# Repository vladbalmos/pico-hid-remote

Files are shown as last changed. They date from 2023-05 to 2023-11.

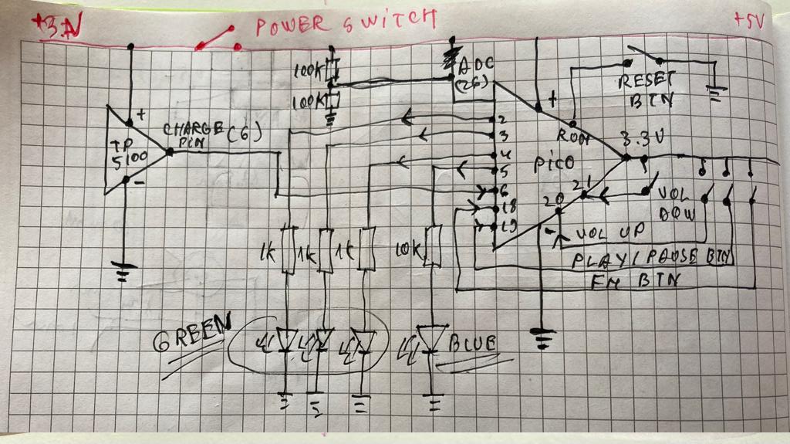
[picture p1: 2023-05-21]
hw/schematic.jpeg

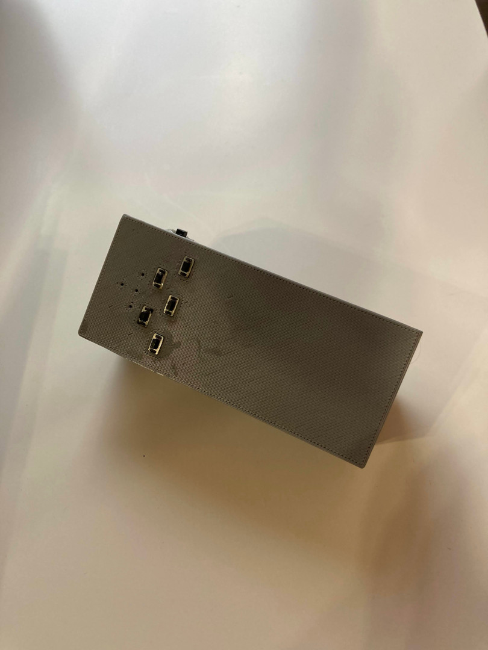
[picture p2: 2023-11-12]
hw/case/case-v1.jpeg

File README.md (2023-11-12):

## HID Bluetooth Remote

HID Bluetooth (BLE) Remote based on a Pico W.

case-v2-cover

## Hardware requirements

* Pico W
* 5 x micro switches
* TP5100 charging module
* micro USB female
* 1 x 18650 lithium battery (for the V1 enclosure)
* 1 x blackberry q10 lithium battery (for the V2 enclosure)
* 1 x 3mm blue LED + 10k resistor
* 3 x 3mm green LED + 3 x 1k resistors
* 2 x 100k resistors
* pico probe (optional)

## Software dependencies

* pico-sdk (1.5.0)
* pico-extras
* opencd (optional)
* pico probe (optional)

## Build

    make build
    
## Install
Via pico probe:

    make install

## Buttons

* FN
    - long press - turn off
    - double press - show baterry level
    
* PLAY
    - wakeup from sleep if sleeping
    - toggle play/pause
    
* VOL UP
    - increase volume

* VOL DOWN
    - decrease volume

* RESET
    - reset PICO
    
## Behaviour
    
On startup the device is discoverable for one minute, after which, if not paired, the device will go to sleep to preserve battery.

If the device is paired, discoverability is turned off until disconnected.

Once paired, the device will go to sleep if no button press was detected in 10 minutes in order to preserve battery.

### LEDs

* blue
    - flashes while not connected and in pairing mode
    - off once paired
    
* 3 x green
    - show battery level
    - if battery level <= 5% the last led in will flash for 5 seconds

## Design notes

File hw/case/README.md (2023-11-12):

There's two versions for the enclosure, the original designed around a 18650 battery and a protoboard and an updated version designed for a proper PCB and a battery taken from an old BlackBerry Q10 phone.

Both versions have their issues. The V1's overall size is a little to small for the amount of wires inside and the thin walls make it flex and doesn't seal properly. Also the buttons had to be superglued to stay in place.

The V2 is a really tight fit because again I didn't account for the size of the jumper wires. Also some filing is required on the lid interior because I forgot to cut out some interior features of the model. If you're planning to print the second version, I recommend printing with supports on the inner side, in my case I printed it on the outer side with supports which were really hard to remove and required filing.

[Case V1](https://github.com/vladbalmos/pico-hid-remote/blob/master/hw/case/case-v1.jpeg)

[Case V2](https://github.com/vladbalmos/pico-hid-remote/blob/master/hw/case/case-v2.jpeg)

[V1 vs V2](https://github.com/vladbalmos/pico-hid-remote/blob/master/hw/case/case-v1-vs-v2.jpeg)

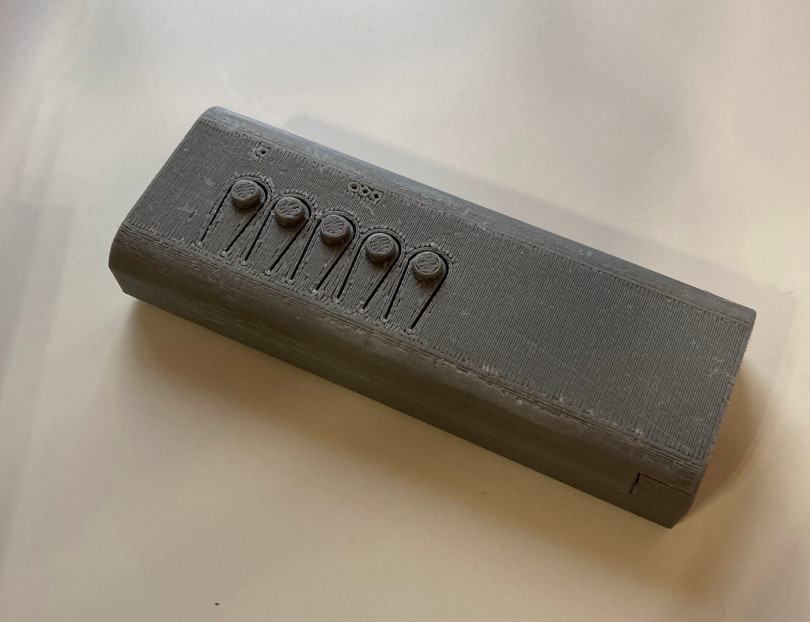
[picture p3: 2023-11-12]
hw/case/case-v2-cover.jpeg

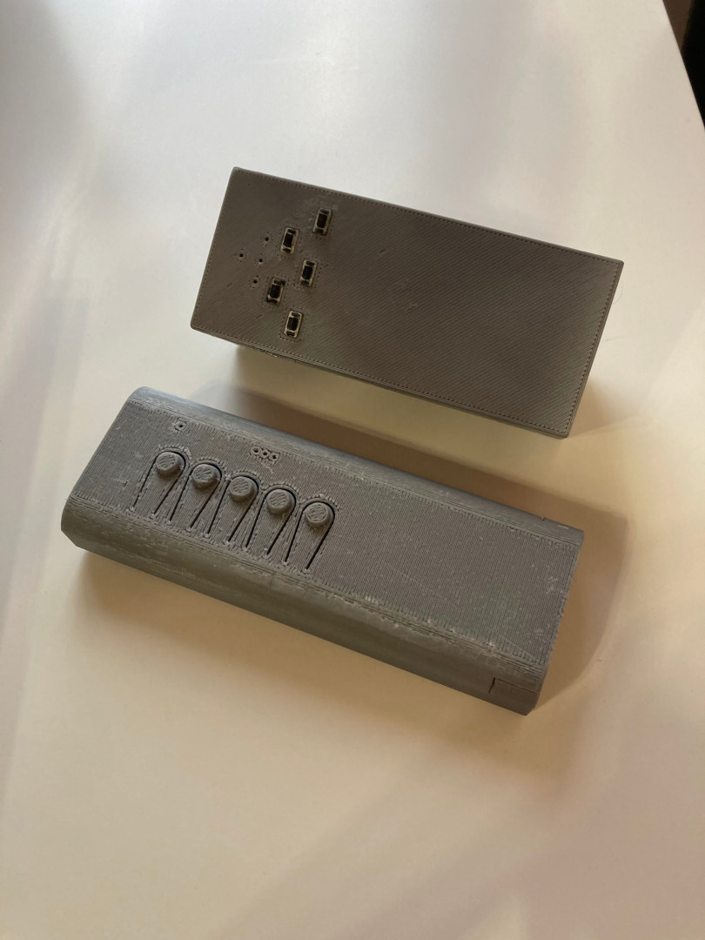
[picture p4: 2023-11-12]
hw/case/case-v1-vs-v2.jpeg

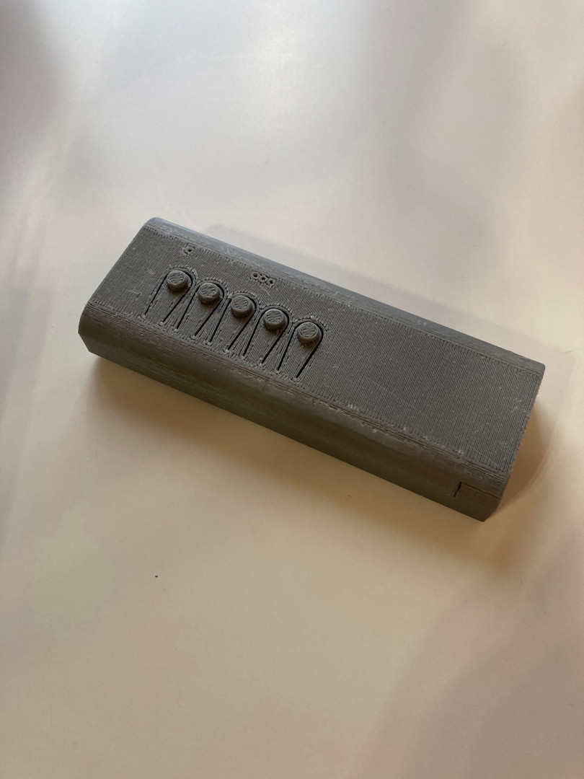
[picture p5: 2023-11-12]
hw/case/case-v2.jpeg

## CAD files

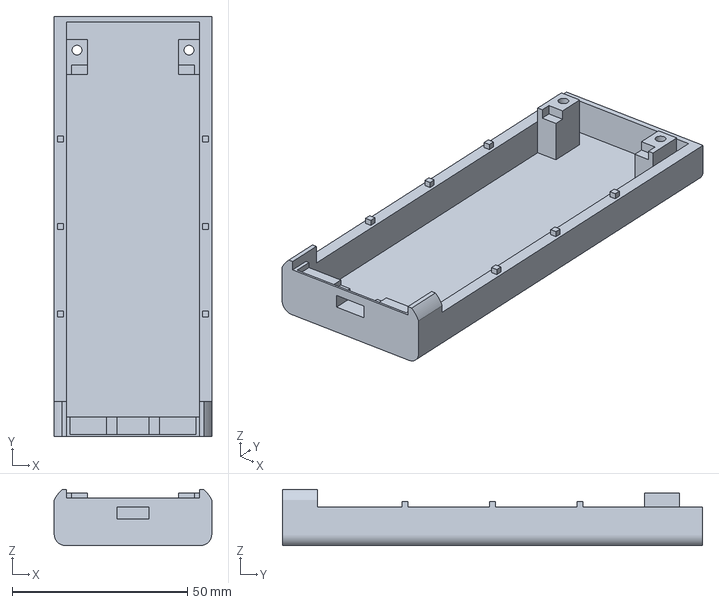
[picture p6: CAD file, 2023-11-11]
hw/case/case_v2-Case_Body.3mf
45.0 x 120.0 x 16.0 mm

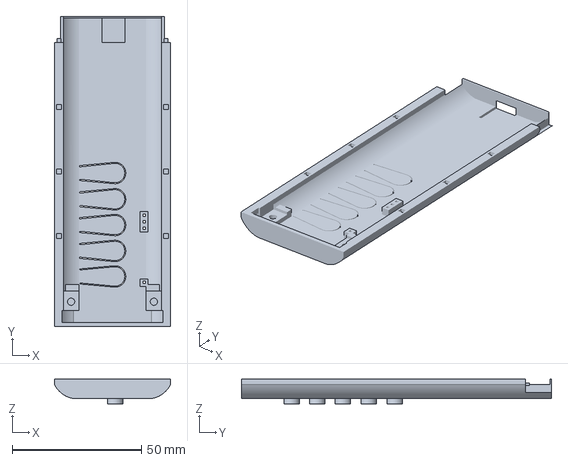
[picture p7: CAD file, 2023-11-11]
hw/case/case_v2-Lid_Body.3mf
45.0 x 120.0 x 9.50 mm

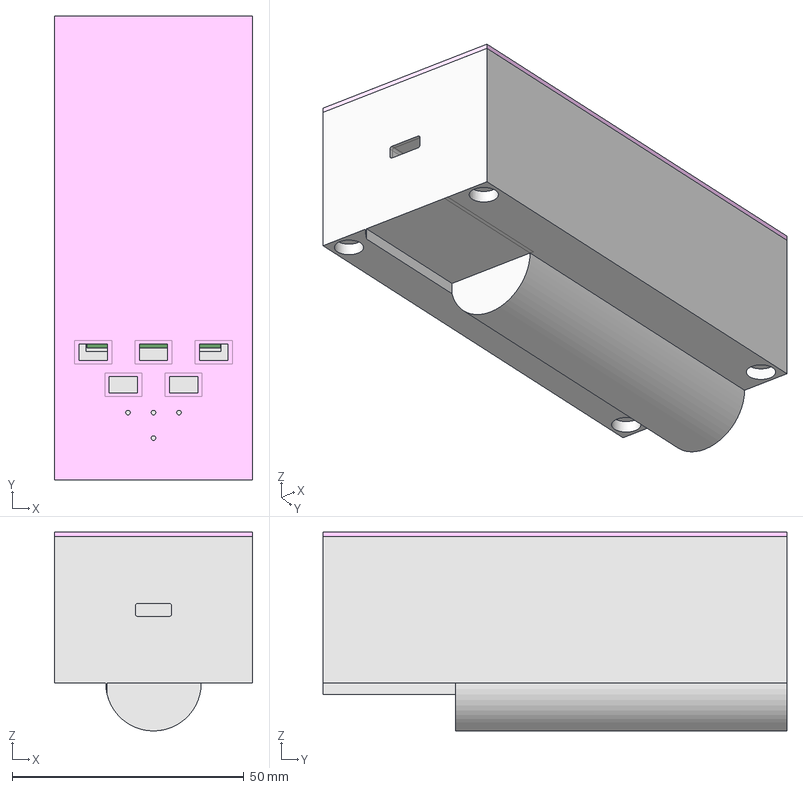
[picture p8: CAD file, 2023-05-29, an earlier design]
hw/case/case.FCStd
42.7 x 100.0 x 42.9 mm
Case_Body
Battery_Body
Body_PCB
Lid_Body

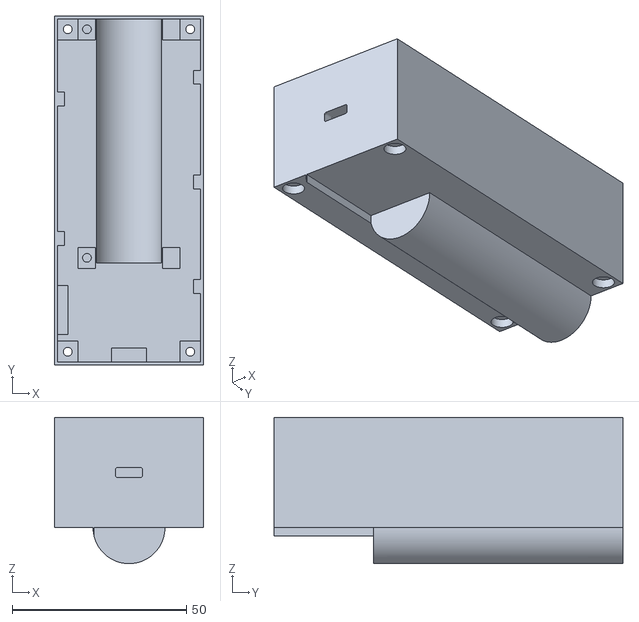
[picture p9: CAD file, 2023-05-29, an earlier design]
hw/case/case-Case_Body.stl
42.7 x 100.0 x 41.9

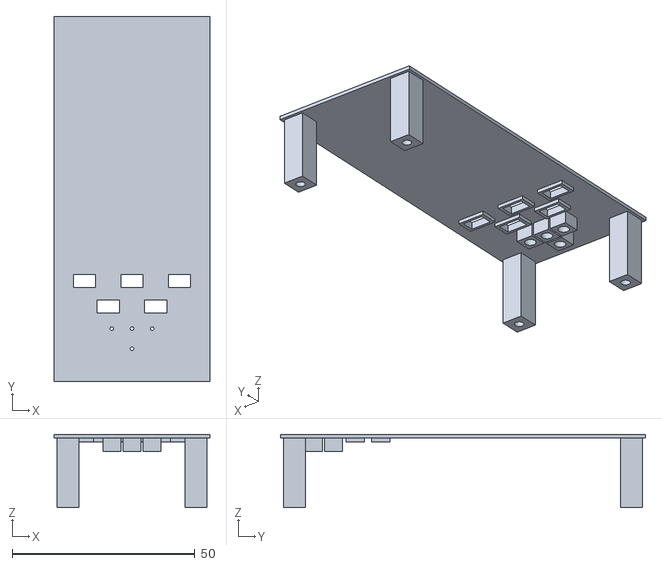
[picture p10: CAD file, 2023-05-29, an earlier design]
hw/case/case-Lid_Body.stl
42.7 x 100.0 x 20.0

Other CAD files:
hw/case/case_v2.FCStd
hw/case/case_v2-Case_Body.stl
hw/case/case_v2-Lid_Body.stl

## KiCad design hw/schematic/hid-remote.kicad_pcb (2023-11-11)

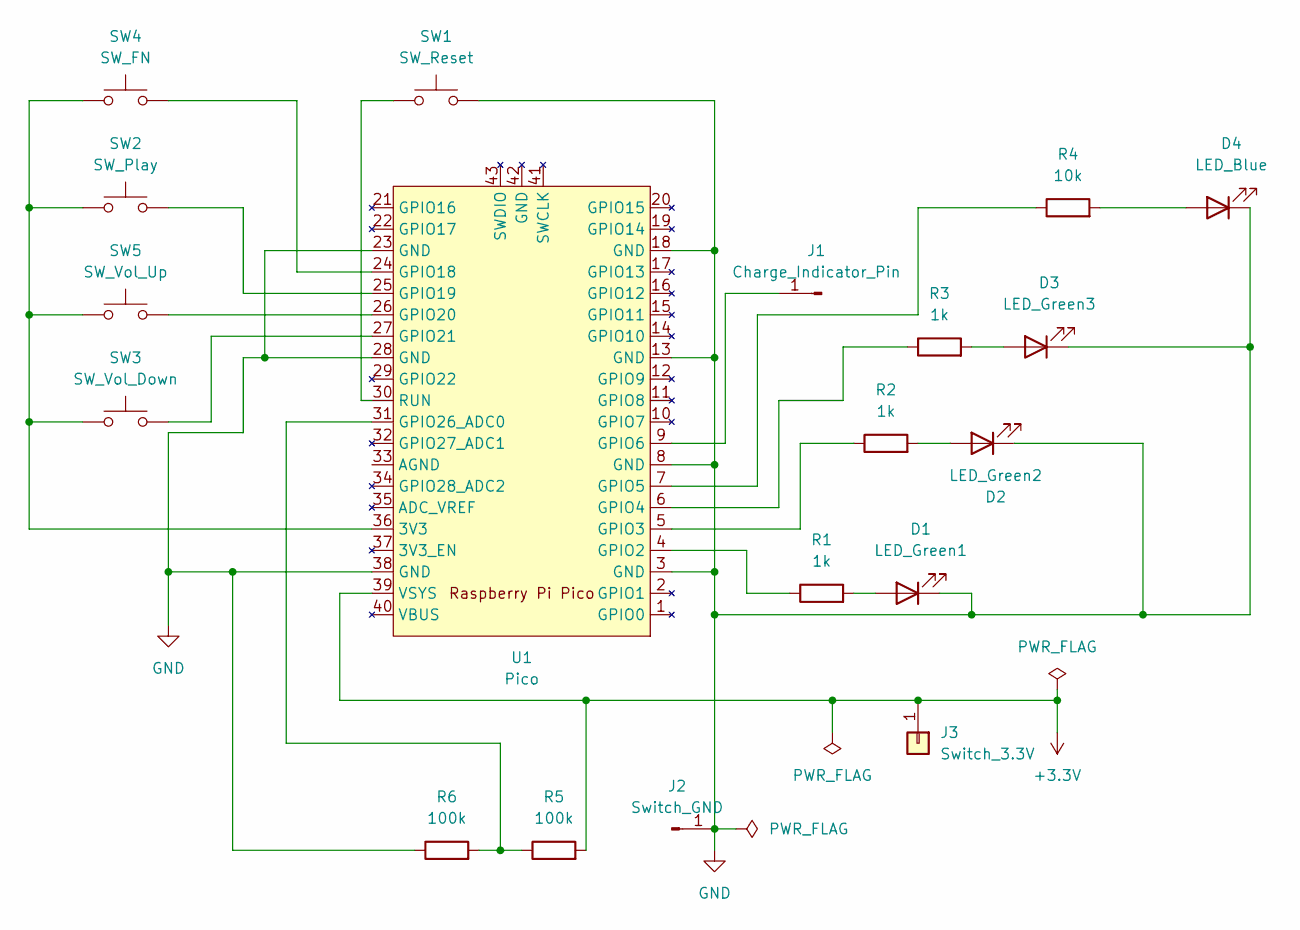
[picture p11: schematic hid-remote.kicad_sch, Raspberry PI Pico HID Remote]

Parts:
D1: LED_Green1; LED_0201_0603Metric_Pad0.64x0.40mm_HandSolder
D2: LED_Green2; LED_0201_0603Metric_Pad0.64x0.40mm_HandSolder
D3: LED_Green3; LED_0201_0603Metric_Pad0.64x0.40mm_HandSolder
D4: LED_Blue; LED_0201_0603Metric_Pad0.64x0.40mm_HandSolder
J1: Charge_Indicator_Pin; PinSocket_1x01_P2.54mm_Vertical
J2: Switch_GND; PinSocket_1x01_P2.54mm_Vertical
J3: Switch_3.3V; PinSocket_1x01_P2.54mm_Vertical
R1, R2, R3: 1k; R_Axial_DIN0204_L3.6mm_D1.6mm_P5.08mm_Horizontal
R4: 10k; R_Axial_DIN0207_L6.3mm_D2.5mm_P10.16mm_Horizontal
R5, R6: 100k; R_Axial_DIN0207_L6.3mm_D2.5mm_P10.16mm_Horizontal
SW1: SW_Reset; SW_Push_3x6x5
SW2: SW_Play; SW_Push_3x6x5
SW3: SW_Vol_Down; SW_Push_3x6x5
SW4: SW_FN; SW_Push_3x6x5
SW5: SW_Vol_Up; SW_Push_3x6x5
U1: Pico; RPi_Pico_SMD_TH

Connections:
+3.3V: J3.1, R5.2, U1.39 (VSYS)
GND: D1.1 (K), D2.1 (K), D3.1 (K), D4.1 (K), J2.1, R6.1, SW1.2, U1.3 (GND), U1.8 (GND), U1.13 (GND), U1.18 (GND), U1.23 (GND), U1.28 (GND), U1.38 (GND)
unnamed: D1.2 (A), R1.2
unnamed: D2.2 (A), R2.2
unnamed: D3.2 (A), R3.2
unnamed: D4.2 (A), R4.2
unnamed: J1.1, U1.9 (GPIO6)
unnamed: SW2.1, SW3.1, SW4.1, SW5.1, U1.36 (3V3)
unnamed: R1.1, U1.4 (GPIO2)
unnamed: R2.1, U1.5 (GPIO3)
unnamed: R3.1, U1.6 (GPIO4)
unnamed: R4.1, U1.7 (GPIO5)
unnamed: SW4.2, U1.24 (GPIO18)
unnamed: SW2.2, U1.25 (GPIO19)
unnamed: SW5.2, U1.26 (GPIO20)
unnamed: SW3.2, U1.27 (GPIO21)
unnamed: R5.1, R6.2, U1.31 (GPIO26_ADC0)
unnamed: SW1.1, U1.30 (RUN)

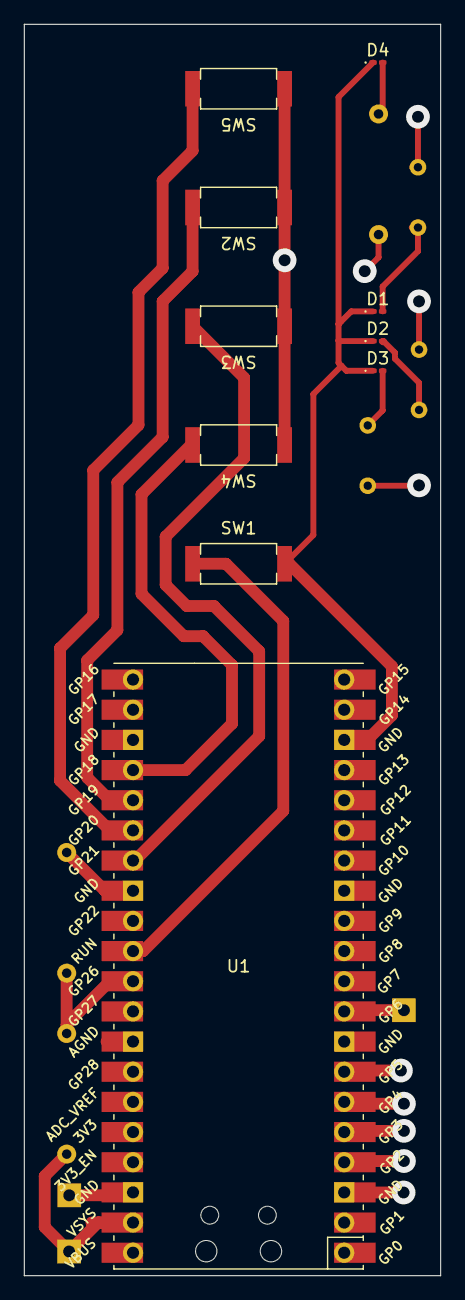
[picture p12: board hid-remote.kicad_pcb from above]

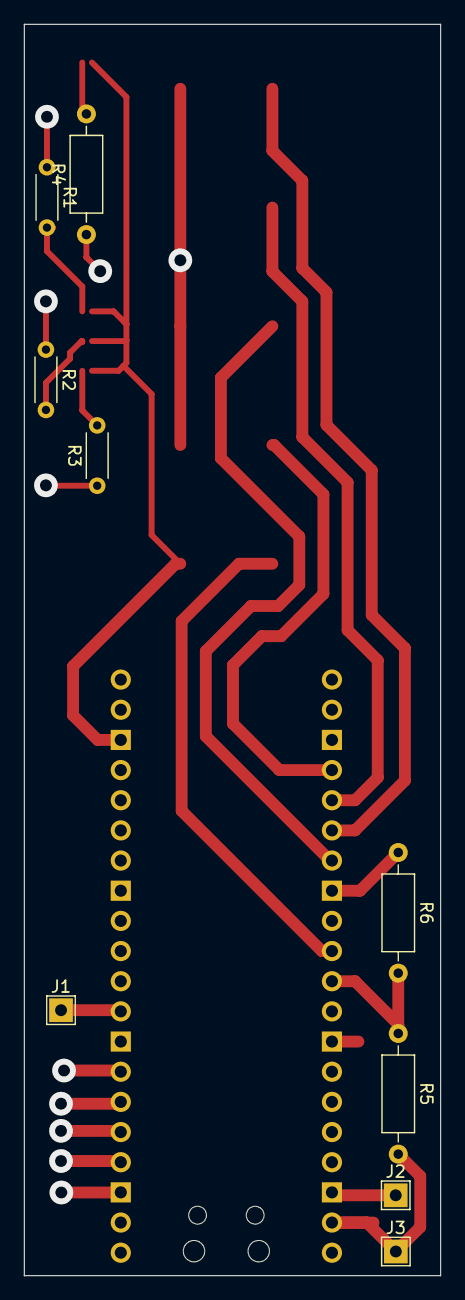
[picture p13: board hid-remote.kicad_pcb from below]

Board: 2 copper layers, 35.1 x 105.4 mm, 19 parts (9 on the bottom side), 18 nets.

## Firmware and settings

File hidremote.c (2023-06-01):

#include <stdio.h>
#include "pico/cyw43_arch.h"
#include "pico/sleep.h"
#include "hardware/clocks.h"
#include "hardware/pll.h"
#include "hardware/xosc.h"
#include "hardware/rosc.h"
#include "pico/util/queue.h"
#include "bt.h"
#include "buttons.h"
#include "control.h"
#include "battery.h"
#include "leds.h"
#include "debug.h"

#define ADC_PIN 26
#define MICRO_SLEEP_MS 10
#define BATTERY_CHECK_INTERVAL_S 10

#define CHARGE_PIN 6

static uint8_t pins[] = {FN_BTN_PIN, PLAY_CTRL_BTN_PIN, VOL_UP_BTN_PIN, VOL_DOWN_BTN_PIN};
static queue_t ctrl_ev_w_queue;
static queue_t ctrl_ev_r_queue;
static uint8_t bat_level;

extern uint8_t ctrl_is_connected;
extern absolute_time_t ctrl_disconnected_at;
extern absolute_time_t ctrl_last_command_at;

static void gpio_irq_handler(uint gpio, uint32_t event) {
    if (event == (GPIO_IRQ_EDGE_RISE | GPIO_IRQ_EDGE_FALL)) {
        return;
    }

    button_t *btn;
    uint8_t btn_action = 0;
    int8_t btn_pin = -1;
    
    btn_debounce(gpio, event, &btn_pin, &btn_action);
    
    if (btn_pin == -1) {
        return;
    }

    btn = btn_get(btn_pin);
    btn->pin = btn_pin;
    
    if (btn_action == BTN_PRESS) {
        btn->pressed_at = get_absolute_time();
    } else {
        btn->released_at = get_absolute_time();
    }
}

static int8_t deep_sleep() {
    // Flush stdio
    uart_default_tx_wait_blocking();
    
    // Prepare for sleep
    leds_turnoff();
    bt_deinit();
    cyw43_arch_deinit();
    ctrl_deinit();
    
    
    // Sleep until GPIO input
    sleep_run_from_rosc();
    sleep_goto_dormant_until_edge_high(PLAY_CTRL_BTN_PIN);
    
    // At this point we've woken up

    // Reset the clocks
    clocks_init();
    
    // Re-init stdio
    stdio_init_all();
    DEBUG("Woken up\n");
    uart_default_tx_wait_blocking();

    // Initialize BT
    if (cyw43_arch_init()) {
        DEBUG("Failed to initialise cyw43_arch\n");
        return -1;
    }
    bat_level = battery_level();
    bt_init(&ctrl_ev_r_queue, &ctrl_ev_w_queue, bat_level);
    ctrl_init(&ctrl_ev_w_queue, &ctrl_ev_r_queue);
    return 0;
}


int main() {
    button_t *btn;
    absolute_time_t now = nil_time;
    uint32_t now_s;
    uint32_t time_diff = 0;
    uint8_t battery_level_published = 0;

    stdio_init_all();

    // Init Bluetooth chipset
    if (cyw43_arch_init()) {
        printf("failed to initialise cyw43_arch\n");
        // TODO: check if power goes down when returning early
        return -1;
    }
    
    // Init buttons gpio pins
    for (uint8_t i = 0; i < 4; i++) {
        gpio_init(pins[i]);
        gpio_set_dir(pins[i], GPIO_IN);
        gpio_set_irq_enabled_with_callback(pins[i], GPIO_IRQ_EDGE_RISE | GPIO_IRQ_EDGE_FALL, true, &gpio_irq_handler);
    }
    
    // Init charge pin
    gpio_init(CHARGE_PIN);
    gpio_set_dir(CHARGE_PIN, GPIO_IN);

    // Init leds
    leds_init();
    
    queue_init(&ctrl_ev_w_queue, sizeof(ctrl_ev_t), 10);
    queue_init(&ctrl_ev_r_queue, sizeof(ctrl_ev_t), 10);

    // Init battery readings
    battery_init(ADC_PIN);
    bat_level = battery_level();
    
    // Init btstack
    bt_init(&ctrl_ev_r_queue, &ctrl_ev_w_queue, bat_level);

    // Init controller
    ctrl_init(&ctrl_ev_w_queue, &ctrl_ev_r_queue);
    
    // Init buttons
    btn_create_array();

    DEBUG("Remote initialized\n");
    leds_show_bt_connecting();
    
    while (1) {
        bt_process_queue();
        ctrl_process_queue();
        now = get_absolute_time();
        now_s = to_ms_since_boot(now) / 1000;

        if (gpio_get(CHARGE_PIN)) {
            DEBUG("Started battery charging. Stopping!\n");
            uart_default_tx_wait_blocking();
            break;
        }
        
        // Start checking battery level 10 seconds after boot
        if (now_s > 10 && bat_level <= 1) {
            DEBUG("Battery low! Please recharge! Stopping!\n");
            uart_default_tx_wait_blocking();
            break;
        }

        if (!ctrl_is_connected) {
            time_diff = absolute_time_diff_us(ctrl_disconnected_at, now) / 1000;
            if (time_diff >= CTRL_DEEP_SLEEP_TIMEOUT_MS) {
                DEBUG("Going to sleep due to lack of remote connection\n");
                deep_sleep();
                leds_show_bt_connecting();
                continue;
            }
        } else {
            // Check battery every 10 seconds
            if ((now_s % BATTERY_CHECK_INTERVAL_S) == 0) {
                if (!battery_level_published) {
                    bat_level = battery_level();
                    bt_set_battery_level(bat_level);
                    battery_level_published = 1;
                    DEBUG("Publishing battery level %d\n", bat_level);
                }
            } else {
                battery_level_published = 0;
            }

            if (ctrl_last_command_at) {
                time_diff = absolute_time_diff_us(ctrl_last_command_at, now) / 1000;
                if (time_diff >= CTRL_CMD_TIMEOUT_MS) {
                    DEBUG("Going to sleep due to inactivity\n");
                    deep_sleep();
                    leds_show_bt_connecting();
                    continue;
                }
            }
        }
        
        btn = btn_get(FN_BTN_PIN);

        if (btn_is_pressed(btn)) {
            if (btn_is_long_press(btn))  {
                btn_handled(btn, now);
                DEBUG("Going to sleep\n");
                if (deep_sleep() == -1) {
                    // Unable to re-initialize hardware
                    panic("Unable to safely wake up from sleep!");
                    break;
                }
                
                leds_show_bt_connecting();
                goto SLEEP;
            } else if (btn_is_double_press(btn)) {
                leds_show_battery_level(bat_level);
                DEBUG("Showing battery level\n");
            }
            goto SLEEP;
        }

        btn = btn_get(PLAY_CTRL_BTN_PIN);
        if (btn_is_pressed(btn)) {
            btn_handled(btn, now);
            ctrl_toggle_play_pause();
            goto SLEEP;
        }

        btn = btn_get(VOL_UP_BTN_PIN);
        if (btn_is_pressed(btn)) {
            btn_handled(btn, now);
            ctrl_vol_up();
            goto SLEEP;
        }

        btn = btn_get(VOL_DOWN_BTN_PIN);
        if (btn_is_pressed(btn)) {
            btn_handled(btn, now);
            ctrl_vol_down();
            goto SLEEP;
        }

        SLEEP:
            sleep_ms(MICRO_SLEEP_MS);
    }
    
    // Stop everything
    leds_turnoff();
    bt_deinit();
    ctrl_deinit();
    cyw43_arch_deinit();
    
    clock_configure(clk_ref,
                    CLOCKS_CLK_REF_CTRL_SRC_VALUE_ROSC_CLKSRC_PH,
                    0,
                    1 * MHZ,
                    1 * MHZ);
    clock_configure(clk_sys,
                    CLOCKS_CLK_SYS_CTRL_SRC_VALUE_CLK_REF,
                    0,
                    1 * MHZ,
                    1 * MHZ);

    xosc_disable();
    rosc_disable();
    clock_stop(clk_peri);
    clock_stop(clk_usb);
    clock_stop(clk_adc);
    clock_stop(clk_rtc);
    pll_deinit(pll_sys);
    pll_deinit(pll_usb);
    clock_stop(clk_sys);
    clock_stop(clk_ref);
    return 0;
}

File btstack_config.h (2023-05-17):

#ifndef _PICO_BTSTACK_BTSTACK_CONFIG_H
#define _PICO_BTSTACK_BTSTACK_CONFIG_H

// BTstack features that can be enabled
#define ENABLE_LE_PERIPHERAL
#define ENABLE_LE_CENTRAL
#define ENABLE_L2CAP_LE_CREDIT_BASED_FLOW_CONTROL_MODE
#define ENABLE_PRINTF_HEXDUMP
#define ENABLE_SCO_OVER_HCI

// BTstack configuration. buffers, sizes, ...
#define HCI_OUTGOING_PRE_BUFFER_SIZE 4
#define HCI_ACL_PAYLOAD_SIZE (1691 + 4)
#define HCI_ACL_CHUNK_SIZE_ALIGNMENT 4
#define MAX_NR_AVDTP_CONNECTIONS 1
#define MAX_NR_AVDTP_STREAM_ENDPOINTS 1
#define MAX_NR_AVRCP_CONNECTIONS 2
#define MAX_NR_BNEP_CHANNELS 1
#define MAX_NR_BNEP_SERVICES 1
#define MAX_NR_BTSTACK_LINK_KEY_DB_MEMORY_ENTRIES  2
#define MAX_NR_GATT_CLIENTS 1
#define MAX_NR_HCI_CONNECTIONS 2
#define MAX_NR_HID_HOST_CONNECTIONS 1
#define MAX_NR_HIDS_CLIENTS 1
#define MAX_NR_HFP_CONNECTIONS 1
#define MAX_NR_L2CAP_CHANNELS  4
#define MAX_NR_L2CAP_SERVICES  3
#define MAX_NR_RFCOMM_CHANNELS 1
#define MAX_NR_RFCOMM_MULTIPLEXERS 1
#define MAX_NR_RFCOMM_SERVICES 1
#define MAX_NR_SERVICE_RECORD_ITEMS 4
#define MAX_NR_SM_LOOKUP_ENTRIES 3
#define MAX_NR_WHITELIST_ENTRIES 16
#define MAX_NR_LE_DEVICE_DB_ENTRIES 16

// Limit number of ACL/SCO Buffer to use by stack to avoid cyw43 shared bus overrun
#define MAX_NR_CONTROLLER_ACL_BUFFERS 3
#define MAX_NR_CONTROLLER_SCO_PACKETS 3

// Enable and configure HCI Controller to Host Flow Control to avoid cyw43 shared bus overrun
#define ENABLE_HCI_CONTROLLER_TO_HOST_FLOW_CONTROL
#define HCI_HOST_ACL_PACKET_LEN 1024
#define HCI_HOST_ACL_PACKET_NUM 3
#define HCI_HOST_SCO_PACKET_LEN 120
#define HCI_HOST_SCO_PACKET_NUM 3

// Link Key DB and LE Device DB using TLV on top of Flash Sector interface
#define NVM_NUM_DEVICE_DB_ENTRIES 16
#define NVM_NUM_LINK_KEYS 16

// We don't give btstack a malloc, so use a fixed-size ATT DB.
#define MAX_ATT_DB_SIZE 512

// BTstack HAL configuration
#define HAVE_EMBEDDED_TIME_MS

// map btstack_assert onto Pico SDK assert()
#define HAVE_ASSERT

// Some USB dongles take longer to respond to HCI reset (e.g. BCM20702A).
#define HCI_RESET_RESEND_TIMEOUT_MS 1000

#define ENABLE_SOFTWARE_AES128
#define ENABLE_MICRO_ECC_FOR_LE_SECURE_CONNECTIONS

#define HAVE_BTSTACK_STDIN

// To get the audio demos working even with HCI dump at 115200, this truncates long ACL packetws
//#define HCI_DUMP_STDOUT_MAX_SIZE_ACL 100

#ifdef ENABLE_CLASSIC
#define ENABLE_L2CAP_ENHANCED_RETRANSMISSION_MODE
#endif

#endif // MICROPY_INCLUDED_EXTMOD_BTSTACK_BTSTACK_CONFIG_H

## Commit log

2023-05-19 Add battery related logic
2023-05-21 Add schematic
2023-05-21 Change min / max battery thresholds
2023-05-29 Add case
    [case-Case_Body.stl, case-Lid_Body.stl, case.FCStd]
2023-06-01 Flash bt connecting led after deep sleep due to input timeout
2023-06-19 Update battery level min threshold
2023-11-11 Add schematic, pcb & case
    [case_v2-Case_Body.3mf, case_v2-Case_Body.stl, case_v2-Lid_Body.3mf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]
2023-11-12 Add case descriptions and pictures
